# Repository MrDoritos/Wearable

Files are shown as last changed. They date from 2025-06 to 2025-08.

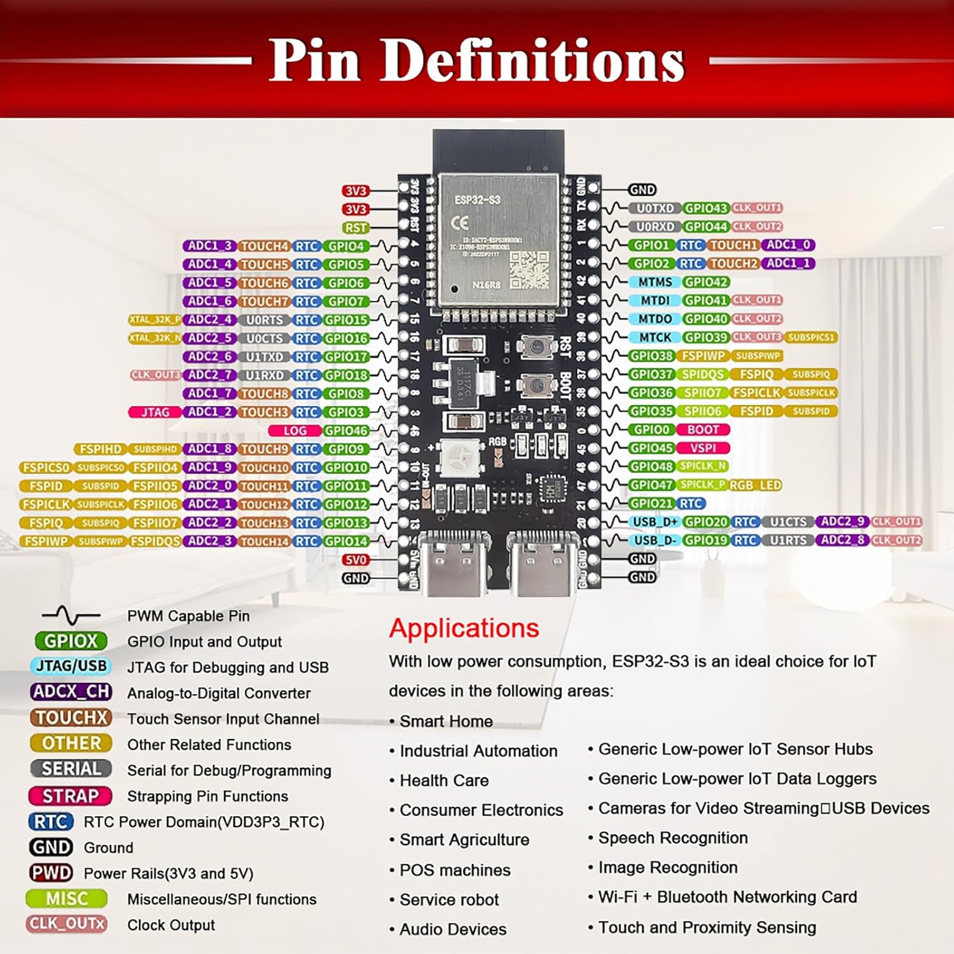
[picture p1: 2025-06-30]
Pics/ESP32 S3 Pinout - 8150a4JlqrL._AC_SL1500_.jpg

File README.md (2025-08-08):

# Wearable

Open source activity and environment tracking and logging device. Works fully offline.

## Features

- GPS location and time synchronization
- Humidity, temperature, and pressure monitoring
- Monitor the level of various gases, such as CO, CO2, VOCs, NH3, NO2, and other hydrocarbons
- UV exposure tracking
- 128x128 OLED display, for high contrast and low power draw
- Piezo and haptic user feedback
- Accelerometer, gyroscope, magnetometer information
- Logging to SD card
- Screen timeout and input lock
- Automatic screen brightness from the ambient light sensor
- Heart rate, blood oxygen (SpO2), and breathing rate
- Minimal loading time

## User interface

- GPS map (only plotted, no map)
- Travel distance and pedometer (step counter)
    - Also available in the stopwatch, which offers splits and history
- Log view
    - Short term, about 10s of information
    - Long term, any amount of information at any specified interval
- Delay free, low latency interface
- Full screen clock interface
- Battery level and time and date visible
- Dynamic interface layout, the size of elements can change

## What's missing

A lot, only a month of programming really went into it. It wasn't sloppy though, and it is quite easy to add and remove features. Some power saving features are missing entirely.

## How much

$200 in parts, but sewing and 3D printing will take some time.

## Parts

- ESP32 S3
- TLV1117 3.3V LDO SOT-223 regulator
- JST 500 or 1200 mAh battery
- GME128128 I2C SH1107 1.5" Monochrome OLED
- BME688
- BerryGPS-IMU v4
- 10mm Piezo, 10mm Vibration motor
- 5x 4.25mm SMD buttons
- 30 AWG silicone wire
- 34 AWG enameled wire
- Stretchy fabric, stretchy thread, non-strechy thread
- MAX30102
- LTR390-UV

Resin printed button caps.

3D printed fabric frames and button holder.

It is best to remove unnecessary connectors.

## In the future

Not waterproof. Most sensors can move to a single board. MAX30102 can be minified. Buttons could be silicone. No frame for the LTR390-UV prevents consistent light measurements. No ammeter to track battery usage.

## Why

Internship project

## Credits

- DFRobot, MAX30102, BMP388
- RocketManRC, u-blox-m8
- Adafruit, LTR390, LSM6DSL, LIS3MDL, inspiration for display driver
- Mozilla, CSS documentation
- Espressif, ESP IDF, HAL for ESP32 S3

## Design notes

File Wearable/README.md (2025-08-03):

# Source for ESP32 controller for Wearable

`g++ imgconv.cpp -o imgconv.o && ./imgconv.o 1 1 ../fonts/fixedsys-excelsior-301.ttf_16x16.png`

`objcopy -I binary -O elf64-x86-64 --rename-section .data=.rodata,alloc,load,readonly,contents fixedsys.bin binary.o`

`g++ binary.o emulator.cpp -o emulator.o console/console.ansi.cpp -g -z noexecstack`

## To-Do

- [ ] UI library
    - [x] Layout
    - [x] Auto sizing
    - [x] Display timeout
    - [ ] Overlays
    - [ ] Popovers
    - [ ] Footer
    - [ ] Focus
- [ ] ESP32
    - [x] Basic functions
        - [x] Display
        - [x] Buttons
        - [x] 3.7v \- 4.2v input
        - [x] Battery sense
    - [ ] Display interface
        - [ ] Async buffer flush
        - [x] Rotation
        - [ ] Screen wake on arm lift and hold
    - [ ] Vibration
        - 3.3V, starting voltage 2.3V
        - less than 75mA, starting current 120mA
    - [ ] Buzzer
    - [ ] LED status
- [ ] Logging
    - [x] SD Card
        - [x] Remaining / total size
        - 3.3v
        - CS pullup to 3.3v permanently, if display remains I2C
    - [ ] Sync GPS time to exported log
- [ ] Sensors
    - [ ] GPS IMU
        - [ ] Magnetometer
            - 0x1C
            - LIS3MDL
        - [x] Gyroscope and Accelerometer
            - 0x6A
            - LSM6DSL
        - [ ] Barometer
            - 0x77
            - BME388
        - [x] GPS
            - 3.3V
            - 0x42
            - CAM-M8
        - [x] GPS time sync
        - 0.040A @ 5v -> 0.2W
    - [ ] LTR-390 UV
        - [ ] UV daily exposure alert
        - [x] Ambient light for auto brightness
        - 400 kHz I2C
        - 3.3V input voltage
        - 100 uA max duty cycle
        - 1 uA standby
        - 5-10ms standby to active
        - [x] UVS/ALS
            - 13 - 20 bits resolution
            - 1:18,000,000 dynamic range
        - UV spectral response 300-350 nm
        - 1 field at a time, mode switch required
    - [ ] BME688
        - [ ] CO2eq ppm
        - [ ] IAQ (0 - 500)
        - [ ] bVOC ppm
            - Breath VOCs
        - [ ] Gas scan results (%)
            - Hydrogen sulfide (H2S)
            - Ethanol (EtOH)
            - Carbon monoxide (CO)
            - 10 to 30 seconds
        - [ ] Humidity (0-100%)
            - accuracy 3%
        - [ ] Temperature
            - 0.01 C output resolution (0.5C accuracy 0-65C)
        - [ ] Pressure (0 - 200000 Pa)
            - 0.18 Pa output resolution (1.2cm)
        - 3.9 mA gas scan
        - 90 uA P/T/H
    - [ ] MICS-6814
        - [ ] Gases
            - [ ] Carbon monoxide (CO) (1-1000 ppm)
            - [ ] Nitrogen dioxide (NO2) (0.05 - 10 ppm)
            - [ ] Ethanol (C2H5OH) (10-500 ppm)
            - [ ] Hydrogen (H2) (1-1000 ppm)
            - [ ] Ammonia (NH3) (1-500 ppm)
            - [ ] Methane (CH4) >1000ppm
            - [ ] Propane (C3H8) >1000ppm
            - [ ] Iso-butane (C4H10) >1000ppm
        - [x] Reality
            - [x] CO (RED reducing gases)
            - [x] NO2 (OX oxidizing gases)
            - [x] NH3
            - Only relative readings. Typical resulting voltages are CO=2.4V NO2=1.7V NH3=2.2V. May work on 3.3v with resistor swapping
            - Heating current is 30mA.. 88mW (5V)
            - Must be read with analog
    - [ ] MAX30102
        - Onboard 3.3V regulator
        - 600 uA
        - 0.7 standby
        - HbO2 oxygenated hemoglobin absorbs infrared
        - Internal temperature sensor
            - 1 C accuracy (-40 - 85C)
        - 400kHz I2C
- Power by module
    - ESP32
        - 40 mA
        - 3.3V reg
    - GPS
        - 40 mA
        - VBAT possible
    - MAX30102
        - 1 mA
        - 3.3V reg
    - GME128128
        - 60 mA
        - VBAT ok
    - BME688
        - 4 mA
        - VBAT possible
    - MiCS-6814
        - 30 mA
        - VBAT possible
    - LTR390-UV
        - 1 mA
        - VBAT possible, may require 3.3v?
    - SD Card
        - 100 mA default mode, verify!
    - Haptics
        - 60 mA.. use VBAT if possible

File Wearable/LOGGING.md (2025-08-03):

# Logging

### Polling Rates

- Each module should synchronize their fields?
- How expensive are SD card flushes?
- Long term data can use an additional buffer, these are for immediate information.
- Screen flush always blocks 36ms, all UI operations block for ~50ms total, but can be split up.
- Sample 2x the frequency of the desired field required to be processed
- I planned on having the polling rate be configured in the UI, without element focus it can't be done
- Time stretching with display on is okay, since with display off it's not an issue

Module|Log Field|Polling Rate|Buffer Size
------|---------|------------|-----------
Battery|Voltage|1000ms (1Hz)|10
MiCS-6814|CO Voltage|1000ms (1Hz)|10
-|NH3 Voltage|-|10
-|NO2 Voltage|-|10
CAM-M8|Latitude|1000ms (1Hz)|100
-|Longitude|-|100
-|Altitude|-|10
-|Bearing|-|10
-|PDOP|-|10
-|Ground Speed|-|10
-|Horizontal Accuracy|-|10
-|Vertical Accuracy|-|10
-|Time Accuracy|-|10
-|Odometer|-|10
IMU|Accelerometer X|10ms (100Hz)|1000
-|Accelerometer Y|-|-
-|Accelerometer Z|-|-
-|Gyroscope X|-|-
-|Gyroscope Y|-|-
-|Gyroscope Z|-|-
-|Pedometer|1000ms (1Hz)|10
BME688|Humidity|1000ms (1Hz)|10
-|Temperature|-|-
-|Pressure|-|-
-|VOC|-|-
-|AQI|-|-
-|CO2|-|-
-|Gas Scan H2S|30000ms (0.0333Hz)|10
-|Gas Scan EtOH|-|-
-|Gas Scan CO|-|-
BMP388|Pressure|1000ms (1Hz)|10
LTR390|ALS|1000ms (1Hz)|10
-|Lux|-|-
-|UVS|-|-
-|UVI|-|-
MAX30102|IR value|50ms (20Hz)|200
-|Red value|-|-
-|Heart Rate|1000ms (1Hz)|10
-|SpO2|-|-

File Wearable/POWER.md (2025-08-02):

# Power Usage Information

### Aug 1 2025

#### Current Device List

- ESP32 S3
    - Core 1 idle
    - Core 0, no sleep, 80 MHz
    - ULP core inactive
    - AMS1117 replaced with TLV1117
- TLV1117
    - SOT223 package
    - 3.3v regulator
    - Low Iq
    - LDO
- LP602535
- GPS/IMU
    - CAM-M8
        - 1s/fix
    - LIS3MDL
    - LSM6DSL
    - BME388
- LTR390
    - 16-Bit resolution
    - 25ms measurement rate
- GME128128
    - SH1107

#### TLV1117 3.3V Regulator

Field|Min|Typ|Max|Unit
-----|---|---|---|----
Input Voltage|2||5.5|V
Output Current|||1.1|A
Dropout Voltage 200mA||115||mV
Dropout Voltage 500mA||285||mV
Dropout Voltage 800mA||455||mV
Dropout Voltage 1000mA||570|800|mV
Quiescent Current 0mA||50||μA
Quiescent Current 200mA||150||μA
Quiescent Current 500mA||300||μA
Quiescent Current 800mA||450||μA
Quiescent Current 1000mA||500||μA
Thermal shutdown||165||°C
Thermal reset||145||°C
Operating temperature|-40||125|°C

#### LP602535 500mAh LiPo

Field|Min|Typ|Max|Unit
-----|---|---|---|----
Capacity|500|510||mAh
Energy Capacity||1.85||Wh
Nominal Voltage||3.70||V
Operating Voltage|2.75||4.20|V
Charging Voltage|||4.20±0.050|V
Charging Current|||250|mA
Discharge Current|||500|mA
Discharge Cut-off Voltage||2.75||V
Internal Impedance|||200|mΩ
Cycle Life||500||cycles
Overcharge Detection||4.275||V
Overdischarge Detection||2.75||V
Overcurrent Detection|2||4.5|A
Charge Temperature|0||45|°C
Discharge Temperature|-20||60|°C

#### GPS/IMU

Field|Min|Typ|Max|Unit
-----|---|---|---|----
4.5V on 5V input|39/170|40/170|42/180|mA/mW
3.3V on 5V input|39/130|40/130|44/140|mA/mW
3.3V on 3.3V input|39/130|40/130|42/140|mA/mW

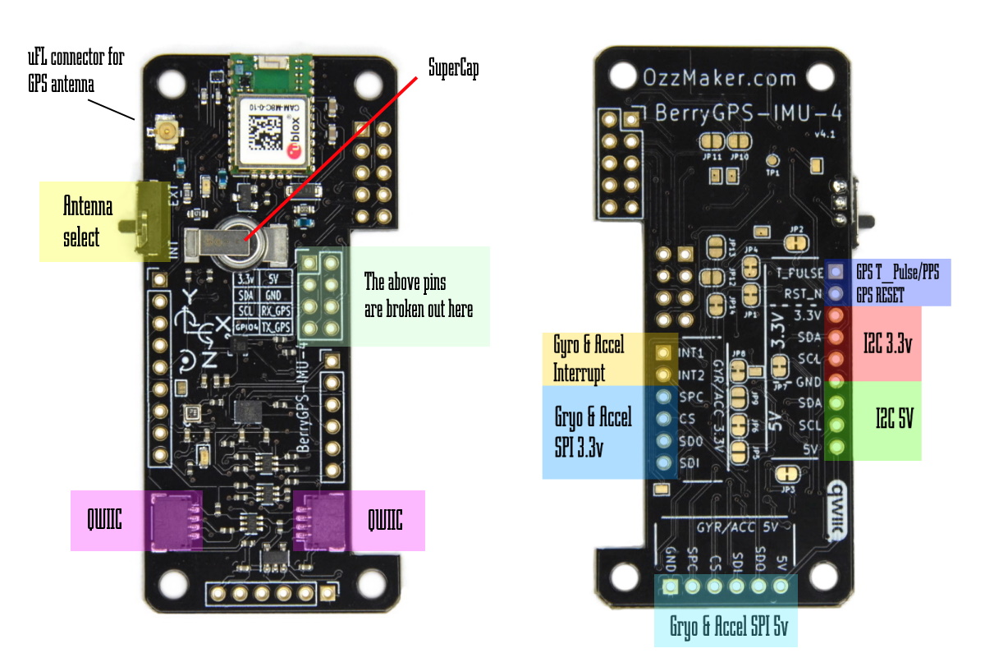
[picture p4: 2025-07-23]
Pics/BerryGPS-IMUv4Pinout2-1600.jpg

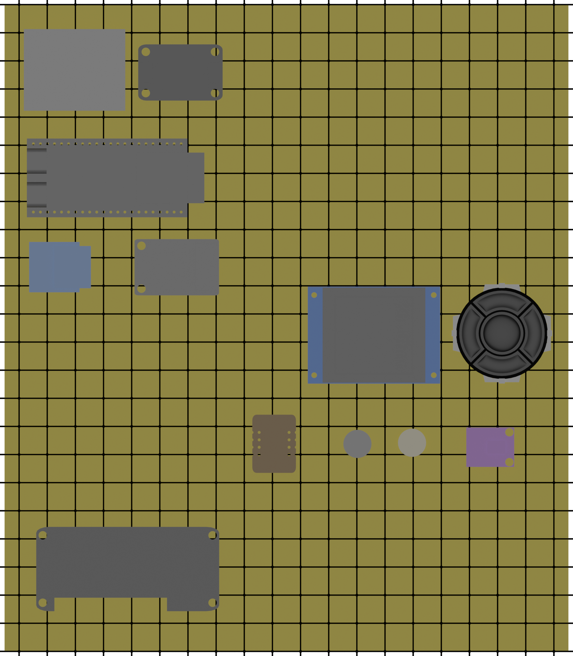
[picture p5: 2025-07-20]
layout2.png

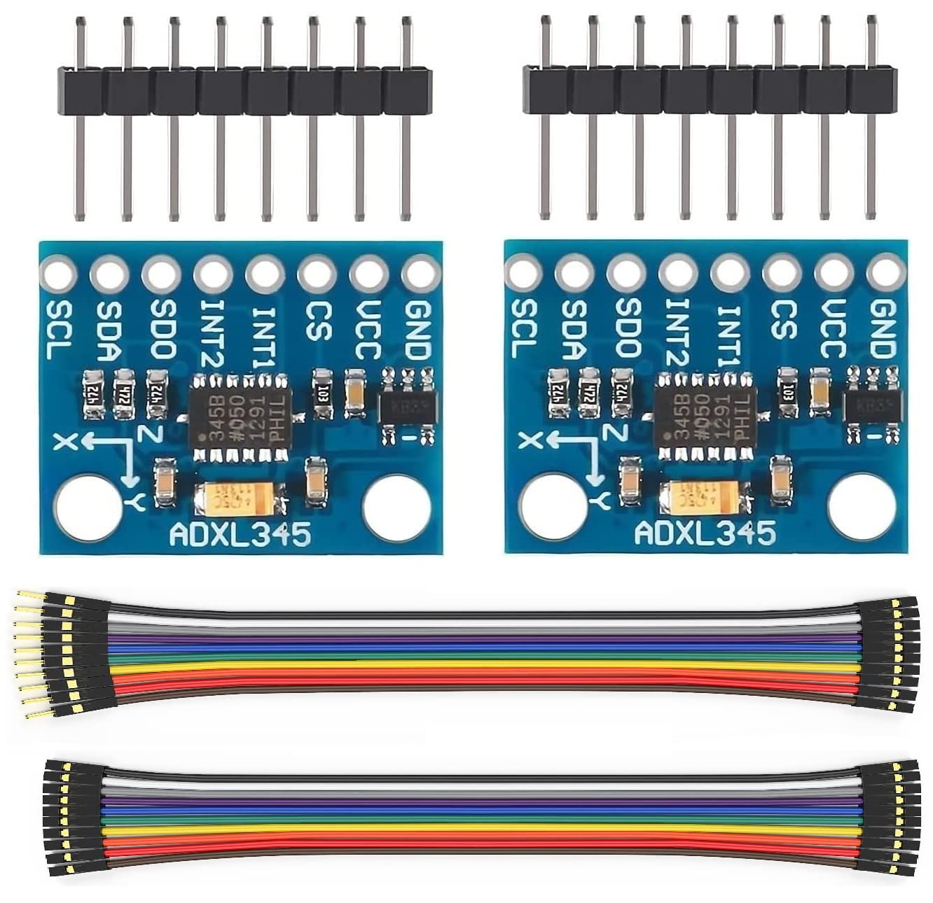
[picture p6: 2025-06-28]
Pics/71FKNZfBxHL._SL1332_.jpg

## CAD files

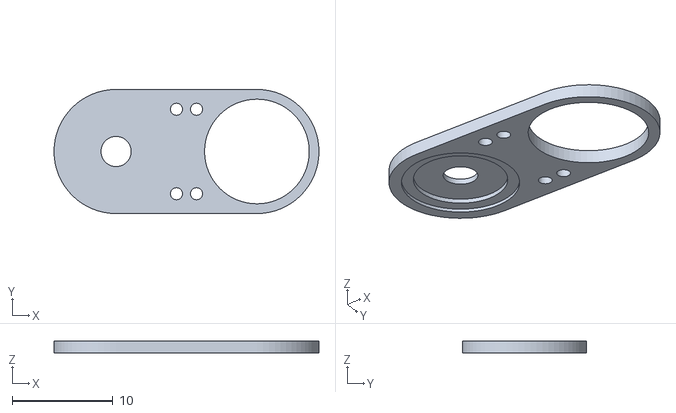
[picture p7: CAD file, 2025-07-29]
stl/Parts Piezo Resonator and Haptics.stl
26.3 x 12.3 x 1.20

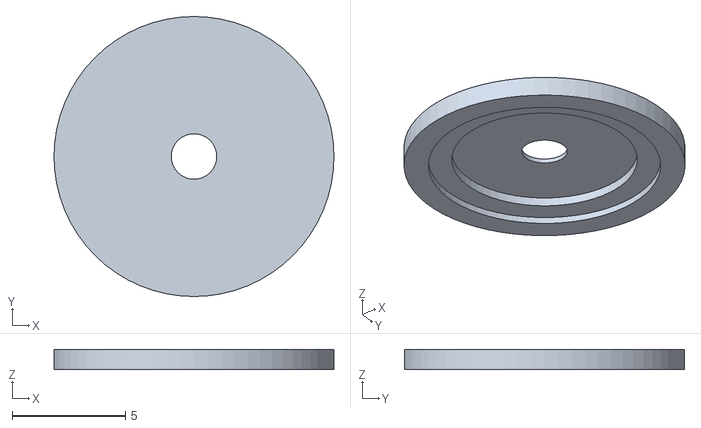
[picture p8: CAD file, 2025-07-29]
stl/Parts Piezo Resonator.stl
12.3 x 12.3 x 0.9

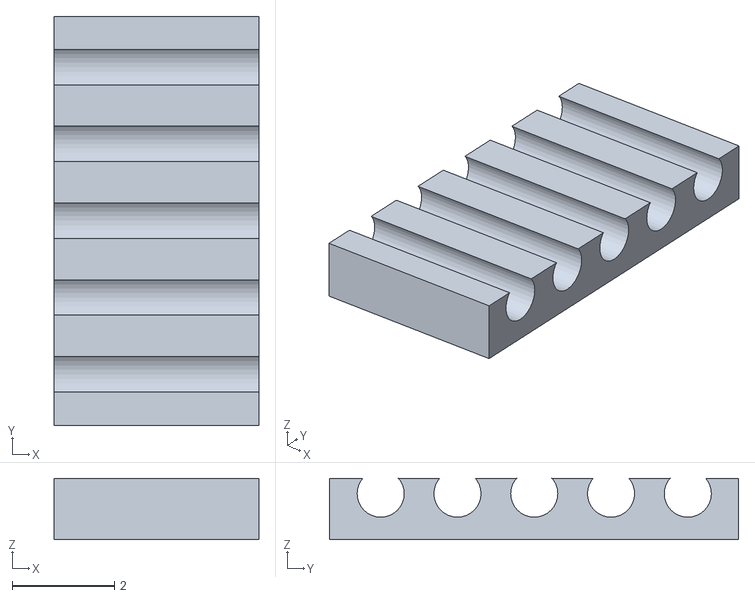
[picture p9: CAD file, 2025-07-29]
stl/Parts Wire Guide.stl
4.00 x 7.99 x 1.20

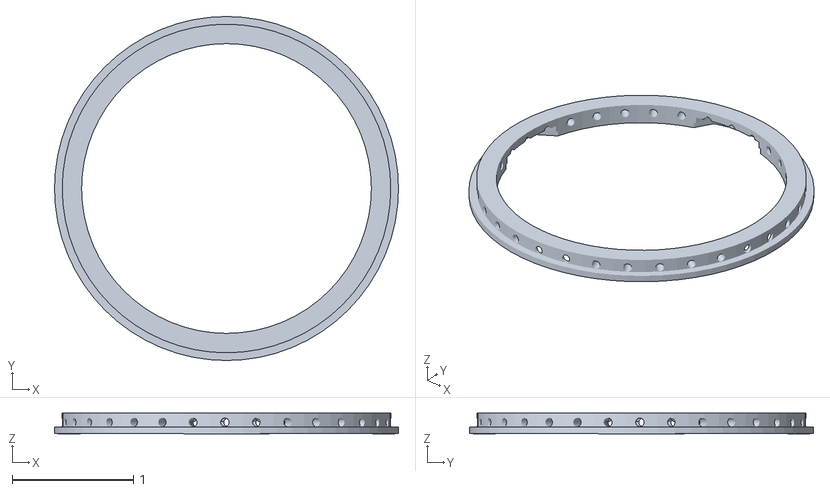
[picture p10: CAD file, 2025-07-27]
stl/dpad frame.stl
2.84 x 2.84 x 0.172

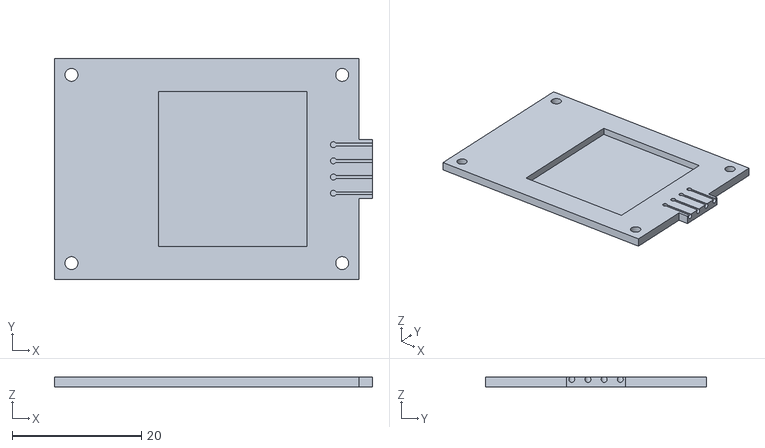
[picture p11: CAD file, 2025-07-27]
stl/Parts OLED Back.stl
49.2 x 34.1 x 1.60

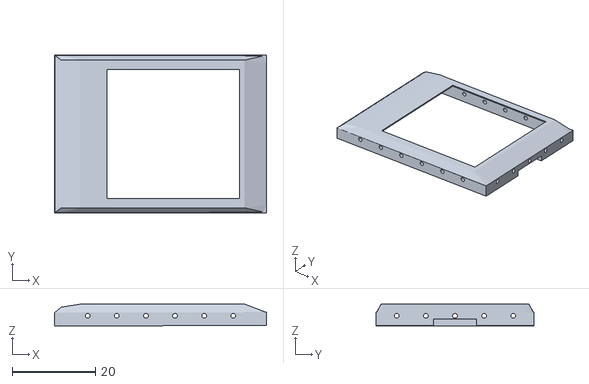
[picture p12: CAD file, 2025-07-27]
stl/Parts OLED Cover.stl
51.0 x 38.0 x 5.24

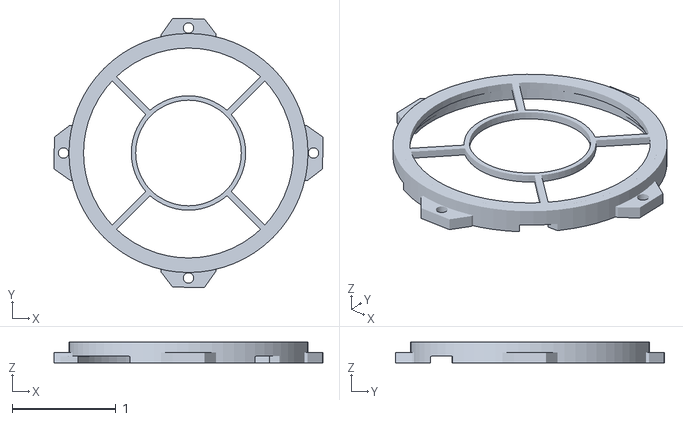
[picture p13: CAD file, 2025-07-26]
stl/dpad holder.stl
2.59 x 2.59 x 0.201

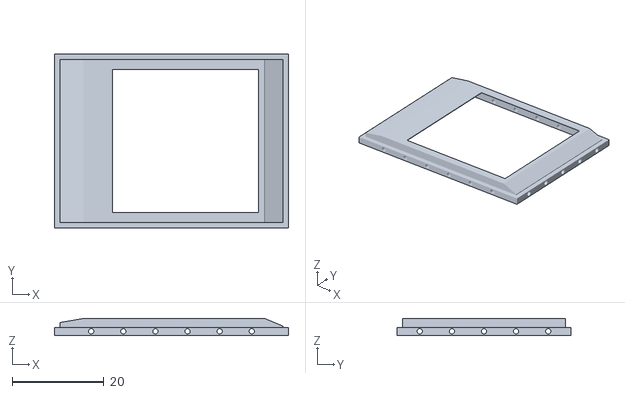
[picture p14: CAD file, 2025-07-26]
stl/Parts OLED Frame New.stl
51.0 x 38.0 x 3.74

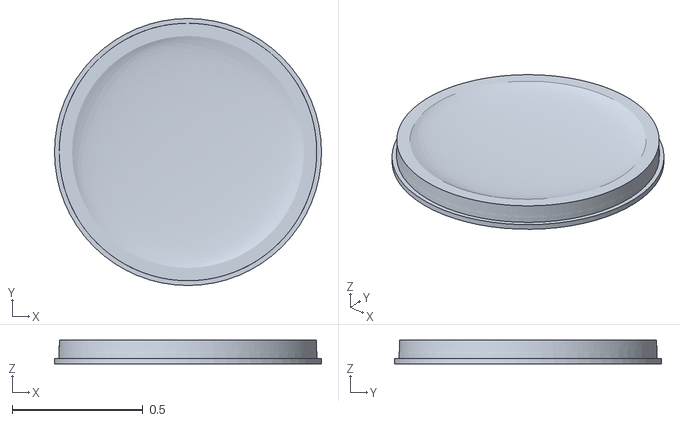
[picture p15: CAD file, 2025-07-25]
stl/dpadenter.stl
1.02 x 1.02 x 0.091

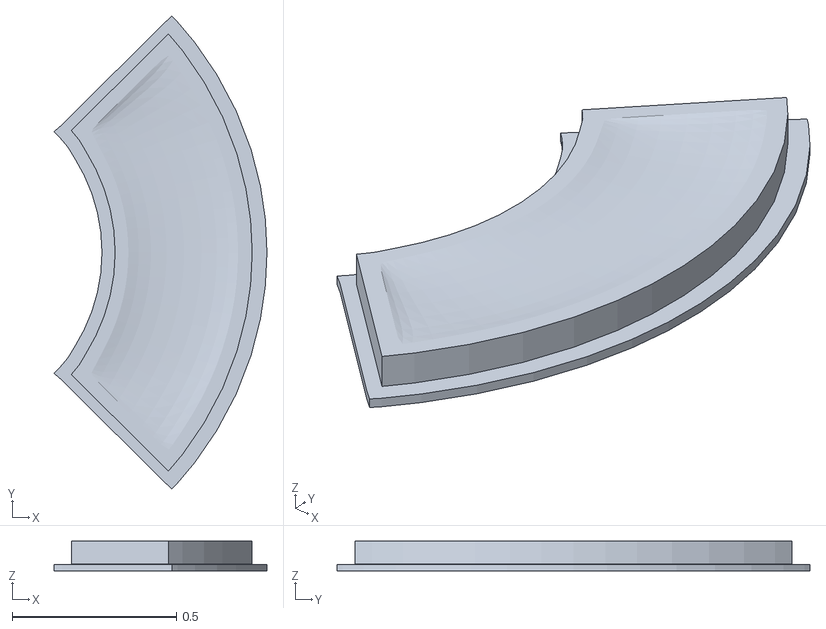
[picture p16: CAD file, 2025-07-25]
stl/dpadarrow.stl
0.648 x 1.44 x 0.0911

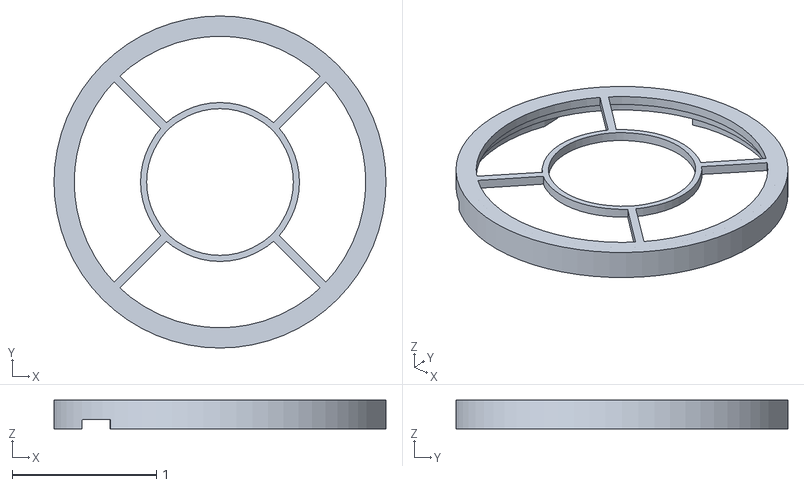
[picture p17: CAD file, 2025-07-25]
stl/Parts SMD Button Housing.stl
2.30 x 2.30 x 0.201

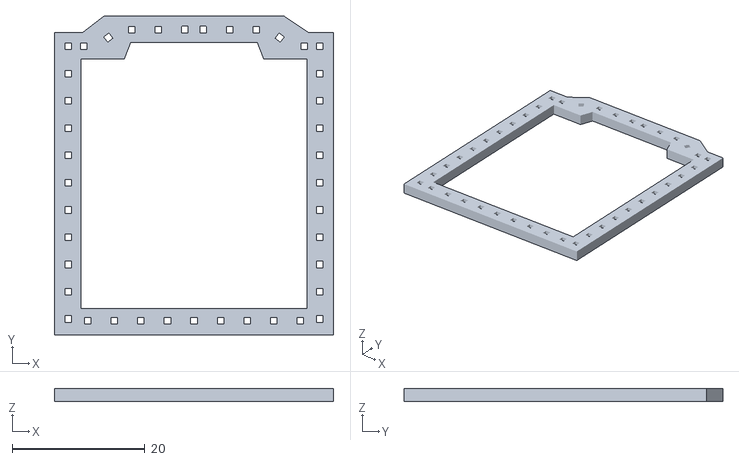
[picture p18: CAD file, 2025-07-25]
stl/Parts OLED Frame.stl
42.0 x 48.0 x 2.00

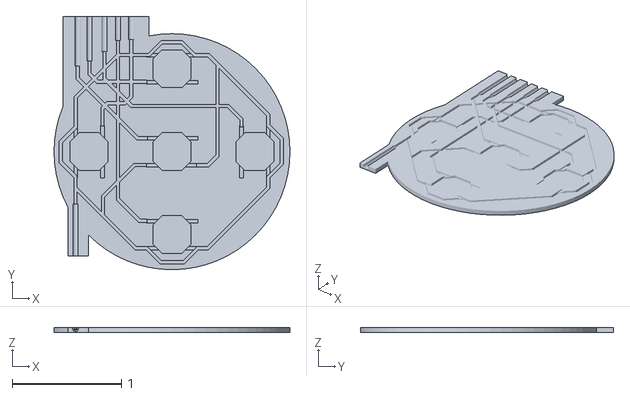
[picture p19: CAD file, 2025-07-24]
stl/dpad Button Board.stl
2.16 x 2.32 x 0.047

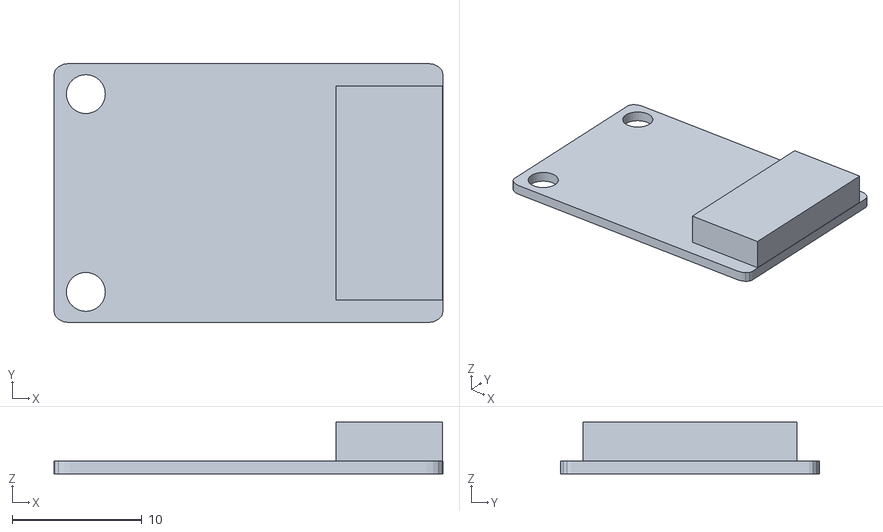
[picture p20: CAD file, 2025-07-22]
stl/PartsBME688_PCB.001.stl
30.0 x 20.0 x 4.00

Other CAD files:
stl/PartsLipo_500mAh.001.stl
stl/PartsMAX30102_PCB.001.stl
stl/PartsSD_card_PCB.001.stl
stl/PartsBerryGPS-IMU_PCB.001.stl
Parts.blend
dpad.blend
stl/ADA254.stl
stl/ADXL345.stl
stl/AHT21.stl
stl/BME280.stl
stl/ESP8266.stl
stl/GT-U7.stl
stl/Lipo 1200.stl
stl/Lipo 500.stl
stl/MAX30102.stl
stl/PartsESP32_PCB.001.stl
stl/PartsHaptic_Motor.001.stl
stl/PartsLTR390-UV_PCB.001.stl
stl/PartsMICS-6814_PCB.001.stl
stl/PartsPiezo.001.stl
stl/dpad.stl
stl/dpadbuttondemo.stl
stl/dpadring.3mf
stl/dpadring.stl
stl/sh1107 inner.3mf
stl/sh1107 inner.stl
stl/sh1107.stl

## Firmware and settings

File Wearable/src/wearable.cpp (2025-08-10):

#include <stdio.h>
#include <inttypes.h>
#include "esp_system.h"
#include "freertos/FreeRTOS.h"
#include "freertos/task.h"

#include "displaybuffer.h"
#include "texture.h"
#include "font.h"
#include "ui.h"
#include "sprites.h"
#include "user_inputs.h"
#include "wbl_func.h"
#include "ui_func.h"
#include "ui_log.h"
#include "display_timeout.h"
#include "gps.h"
#include "ui_gps.h"
#include "gps_imu.h"
#include "ui_imu.h"
#include "wbl_system.h"
#include "ltr390.h"
#include "ui_sysinfo.h"
#include "mics6814.h"
#include "sdcard.h"
#include "peripheral_log.h"
#include "ui_peripheral_log.h"
#include "ui_gps_log.h"
#include "ui_footer.h"
#include "ui_distancetracker.h"
#include "ui_therock.h"

using namespace wbl;
using namespace Sprites;

UI::ElementBaseT<DisplayTexture> test(display);
UI::ElementInlineSpritesT<DisplayTexture, Atlas> spinline(display);
UI::ElementInlineTextT<DisplayTexture, MinifontProvider> TEXT(display, minifont);
UI::ScreenClockT<DisplayTexture> uiclock(display);
UI::ElementRootT<DisplayTexture> uiroot(display);
auto txt = UI::ElementInlineTextT<DisplayTexture, MinifontProvider>(display, minifont);
UI::ElementBatteryT<DisplayTexture> uibattery(display);
UI::ElementDateTimeT<DisplayTexture> uidatetime(display);
UI::ElementBaseT<DisplayTexture> boxtest(display);
UI::ElementBaseT<DisplayTexture> boxtest2(display);
UI::ElementBaseT<DisplayTexture> header(display);
UI::ScreenBaseT<> mainscreen("Main");
UI::ScreenBaseT<> clockscreen("Clock");
UI::ScreenBaseT<> settingscreen("Settings");
LoopBuffer sinelog, squarelog, sawlog, voltlog;
UI::ElementLogT<DisplayTexture, DataLog> e_sinelog(display, sinelog), e_squarelog(display, squarelog), e_sawlog(display, sawlog), e_voltlog(display, voltlog);
UI::ElementLockIconT<DisplayTexture> e_lockicon(display);
UI::ScreenFooterT<> gpsscreen(display, "GPS Info");
UI::ElementGPST<DisplayTexture> uigps(display);
UI::ScreenFooterT<> imuscreen(display, "IMU Info");

UI::ElementIMUT<DisplayTexture> uiimu(display);
UI::ScreenBaseT<> sysinfoscreen("System");
UI::ElementSysInfoT<DisplayTexture> uisysinfo(display);
LoopBuffer colog, nh3log, no2log;
//UI::ElementLogT<DisplayTexture, DataLog> e_colog(display, colog), e_nh3log(display, nh3log), e_no2log(display, no2log);
UI::ElementPeripheralLogAutoT<DisplayTexture, DLMICS6814ST, uint16_t, 0> e_colog(display, wbl::log.mics6814_st);
UI::ElementPeripheralLogAutoT<DisplayTexture, DLMICS6814ST, uint16_t, 1> e_nh3log(display, wbl::log.mics6814_st);
UI::ElementPeripheralLogAutoT<DisplayTexture, DLMICS6814ST, uint16_t, 2> e_no2log(display, wbl::log.mics6814_st);
UI::ScreenFooterT<> gasscreen(display, "Gases");
UI::ElementPeripheralLogAutoT<DisplayTexture, DLBatteryST, uint16_t, 0, UI::ValueBases::Voltage> e_pbatterylogst(display, wbl::log.battery_st);
UI::ElementPeripheralLogAutoT<DisplayTexture, DLBatteryLT, uint16_t, 0, UI::ValueBases::Voltage> e_pbatterylog(display, wbl::log.battery_lt);
UI::ScreenBaseT<> gpsview("GPS");
UI::UIGPSLogT<DisplayTexture, DLCAMM8ST> uigpsst(display, wbl::log.camm8_st);
UI::UIGPSLogT<DisplayTexture, DLCAMM8LT2> uigpslt(display, wbl::log.camm8_lt2);
UI::ElementFooterT<DisplayTexture> uigpsfooter(display, "GPS View");
UI::ScreenBaseT<> distscreen("Tracker");
UI::UIDistanceTrackerT<DisplayTexture> uitracker(display);
UI::ScreenBaseT<> rockscreen("The Rock");
UI::ElementTheRockT<DisplayTexture> e_therock(display);


void demo() {
    wbl::log.update();

    bool has_input = false;
    if (!displayTimeout.lock_key_state(dpad.enter.is_held()))
        has_input = dispatch_input_events(uiroot, dpad);
    else
        dpad.update();

    displayTimeout.update(has_input);

    wbl_system.update();

    uiroot.step();

    static int cnt = 0;
    int64_t t = micros();
    if (cnt++ % 4 == 0) {
        if (wbl::log.ltr390_st.size() > 0) {
            DPLTR390ST stp = wbl::log.ltr390_st.get(-1);
            e_squarelog.push_back(t, stp.uvi*10.0f);
            e_sinelog.push_back(t, stp.lux);
            wbl_system.setDisplayBrightness(stp.lux);
        }
        e_sawlog.push_back(t, (uu)(int(t/5000)%1000));
    }

    if (displayTimeout.is_display_off())
        wbl::log.sleepTillNextPoll();

    #ifdef __linux__
    delay(30);
    #endif
}

void init() {
    //uiroot.setDebug(true);
    WBL_D("UI Init");
    using namespace UI;
    using DElem = UI::ElementT<DisplayTexture>;
    using FElem = UI::ElementFocusT<DisplayTexture>;
    static DElem block(display, "block");
    static DElem inner(display, "inner");
    static DElem block2(display, "area");
    static DElem inlineblock(display, "inline");
    static DElem inlineblock2(display, "sprites");
    static DElem inlineblock3(display, "right");
    static DElem inlineblock4(display, "left");
    static DElem block3(display, "after");

    static FElem focustest(display, "one");
    static FElem focustest2(display, "two");
    static FElem focustest3(display, "three");

    static UI::StyleInfo styles { .display{INLINE}, .width{{25,PERC}}, .height{25} };

    focustest << styles;
    focustest2 << styles;
    focustest3 << styles;
    //settingscreen << focustest;
    //settingscreen << focustest2;
    //settingscreen << focustest3;
    settingscreen << e_sinelog;
    settingscreen << e_squarelog;
    settingscreen << e_sawlog;
    settingscreen << e_voltlog;
    gpsscreen << uigps;
    imuscreen << uiimu;

    StyleInfo screenremaining { .height{92} };

    block << UI::StyleInfo { .height{26} };
    inner << StyleInfo {.height {14}};
    block2 << UI::StyleInfo { .width{32}, .height{26} };
    inlineblock << UI::StyleInfo { .display{INLINE}, .width {40}, .height{26} };
    inlineblock2 << UI::StyleInfo { .align{RIGHT}, .display{INLINE}, .width {32}, .height{20}, .margin{2} };
    inlineblock3 << UI::StyleInfo { .align{RIGHT}, .display{INLINE}, .width {20}, .height{10}, .margin{2} };
    inlineblock4 << UI::StyleInfo { .display{INLINE}, .width{20}, .height{30}, .margin{2} };
    block3 << StyleInfo { .width {30}, .height{20} };
    e_lockicon << StyleInfo{.display{INLINE}, .overflow{AUTO,AUTO}} << "lock";
    uigps << StyleInfo { .height{92}, .overflow{AUTO,AUTO} } << "GPS";
    uiimu << StyleInfo { .height{92} } << "IMU";
    StyleInfo logstyle = { .display{INLINE}, .width {62}, .height{40}, .margin{1} };
    
    uisysinfo << StyleInfo { .height{80} };
    sysinfoscreen << uisysinfo << e_pbatterylog << e_pbatterylogst;

    e_sawlog << logstyle << "saw";
    e_voltlog << logstyle << "volts"; 
    e_sinelog << logstyle << "sine";
    e_squarelog << logstyle << "square";

    StyleInfo gaslogstyle = { .height{32}, .margin{1,0,0,0} };
    e_colog << gaslogstyle << "CO";
    e_nh3log << gaslogstyle << "NH3";
    e_no2log << gaslogstyle << "NO2";
    e_pbatterylog << StyleInfo { .display{INLINE}, .width {96}, .height{32}, .margin{1,1,0,0} } << "VBAT";
    e_pbatterylogst << StyleInfo { .display{INLINE}, .width {30}, .height{32}, .margin{1,0,0,0} } << "VBAT";
    gasscreen << e_colog << e_nh3log << e_no2log;
    distscreen << uitracker;

    uigpslt << StyleInfo { .display{INLINE}, .width {96}, .height{96} } << "GPSLT";
    uigpsst << StyleInfo { .display{INLINE}, .width {32}, .height{64} } << "GPSST";
    gpsview << uigpslt << uigpsst << uigpsfooter;

    uiroot << UI::StyleInfo { .width{128}, .height{128} };

    block << inner;

    /*
    uiroot << block;
    uiroot << block2;
    uiroot << inlineblock;
    uiroot << inlineblock2;
    uiroot << inlineblock3;
    uiroot << inlineblock4;
    uiroot << block3;

    uiroot.resolve_layout();
    */

    //uiroot << Size { 0, 0, 128, 128 };
    test << Origin { 4, 30 };
    //txt << Size { 32, 64, 64, 64 };
    //txt << UI::StyleInfo { .wrap{UI::WRAP} };
    //uiclock << Size { 16, 16, 97, 97 };
    //uiclock << StyleInfo { .width{96}, .height{96}, .margin{16,4} };
    clockscreen << StyleInfo { .width{{100,PERC}}, .height{{100,PERC}} };
    uiclock << StyleInfo { .align{CENTER}, .width{{85,PERC}}, .height{{85, PERC}} };
    TEXT << Origin { 12, 16 };
    test.wrap = (UI::WrapStyle)(UI::WrapStyle::WRAP | UI::WrapStyle::TRIM_SPACE);
    test << Size { 32, 30, 64, 64 };
    spinline << HEART << BATTERY << UI::StyleInfo { .wrap{UI::NOWRAP} };
    //uibattery << Size {0,0,32,16};
    //uidatetime << Size {49, 0, 79, 12} << UI::StyleInfo {.wrap{UI::WRAP}};
    uibattery << UI::StyleInfo { .align{LEFT}, .wrap{NOWRAP}, .display{INLINE}, .overflow{AUTO} };
    uidatetime << UI::StyleInfo { .align{RIGHT}, .wrap{NOWRAP}, .display{INLINE}, .overflow{AUTO} };
    boxtest << Size { 8, 13, 5, 5 };
    boxtest2 << Size { 9, 14, 3, 3 };
    txt << StyleInfo { .align{CENTER}, .width{{70}}, .margin{4} };
    uiclock.use_milliseconds = true;

    TEXT.text = "Hello UI";
    txt.text = "SOME TEST TEXT\n VERY FINE text\n for very small values 0123456789 \% voltage 4.2v !\"#$%&'()*+,-./:;<=>?@[\\]^_`{|}~";

    spinline.on_content_size(nullptr);
    TEXT.on_content_size(nullptr);

    spinline.resolve_layout();
    TEXT.resolve_layout();

    //screenclock.addHeader(header);
    //screenclock << uiclock;
    //screenclocknoheader << txt;

    //uiroot << uibattery;
    //uiroot << uidatetime;
    txt.name = "txt";
    header.name = "header";
    uibattery.name = "battery";
    uidatetime.name = "datetime";
    clockscreen.name = "clockscreen";
    mainscreen.name = "mainscreen";
    uiclock.name = "clock";
    uiroot.name = "root";

    clockscreen.show_header = false;
    rockscreen.show_header = false;

    rockscreen << e_therock;

    header << uibattery;
    header << e_lockicon;
    header << uidatetime;
    //uiroot << header;
    //uiroot << uiclock;
    //uiroot << screenclock;
    //uiroot << screenclocknoheader;
    clockscreen << uiclock;
    mainscreen << txt;
    //mainscreen.set_left(clockscreen);
    //mainscreen.set_right(settingscreen);
    clockscreen.set_left(rockscreen);
    settingscreen.set_left(clockscreen);
    settingscreen.set_right(gpsscreen);
    gpsscreen.set_right(imuscreen);
    imuscreen.set_right(sysinfoscreen);
    sysinfoscreen.set_right(gasscreen);
    gasscreen.set_right(gpsview);
    gpsview.set_right(distscreen);

    uiroot.set_header(header);
    //uiroot.set_screen(mainscreen);
    //uiroot.set_screen(settingscreen);
    //uiroot.set_screen(gpsscreen);
    uiroot.set_screen(imuscreen);
    //uiroot.set_screen(sysinfoscreen);
    //uiroot.set_screen(gasscreen);
    //uiroot.set_screen(gpsview);
    //uiroot.set_screen(distscreen);

    WBL_D("Screen set");

    uiroot.dispatch(EventTypes::CONTENT_SIZE);
    uiroot.resolve_layout();

    WBL_D("First layout");

    for (int i = 0; i < 3; i++)
        wbl_system.getBatteryVoltageMean();
    uibattery.set_battery_level(wbl_system.getBatteryLevel());

    WBL_D("UI endinit");
}

extern "C" {
void app_main() {
    if (wbl_system.init() != ESP_OK) {
        printf("Failed to initialize system\n");
        goto end;
    }
    //wbl_system.acquirePMLock();
    //wbl_system.releasePMLock();
    puts("Initialized system");
    if (mics6814.init() != ESP_OK) {
        printf("Failed to initialize mics6814\n");
        goto end;
    }
    puts("Initialized MiCS-6814");
    wbl_system.beginHapticFeedback(0.5, 500);
    dpad.init();
    puts("Initialized DPAD");
    if (gps.init() != ESP_OK) {
        printf("Failed to initialize gps\n");
        goto end;
    }
    puts("Initialized GPS");
    if (gpsimu.init() != ESP_OK) {
        printf("Failed to initialize imu\n");
        goto end;
    }
    puts("Initialized IMU");
    if (ltr390.init() != ESP_OK) {
        printf("Failed to initialize ltr390\n");
        goto end;
    }
    puts("Initialized LTR390");
    if (sdcard.init() != ESP_OK) {
        printf("Failed to initialize sdcard\n");
        goto end;
    }
    puts("Initialized SDCard");
    if (wbl::log.init() != ESP_OK) {
        printf("Failed to initialize log\n");
        goto end;
    }
    puts("Initialized log");
    init();
    puts("Initialized UI");
    if (display.init() != ESP_OK) {
        printf("Failed to initialize display\n");
        goto end;
    } else {
        printf("Display initialized\n");
        display.clear(0);
        WBL_D("Display clear");
        wbl_system.setDisplayRotation(DISPLAY_ROTATION);
        WBL_D("Display rotation");
        //gps.update();
        //gps.setSystemTime();
        displayTimeout.update(true);
        while (1) {
            demo();
            vPortYield();
        }
    }

    end:;

    fflush(stdout);
    
    delay(1000);

    esp_restart();
}
}

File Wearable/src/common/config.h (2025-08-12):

#pragma once

#include "types.h"

#define I2C_BUS_0_SDA   GPIO_NUM_6
#define I2C_BUS_0_SCL   GPIO_NUM_5

#define I2C_BUS_1_SDA   GPIO_NUM_48
#define I2C_BUS_1_SCL   GPIO_NUM_45

#define I2C_DISPLAY_FREQ 1000000
#define I2C_SH1107_ADDR 0x3C

#define I2C_CAMM8_FREQ 400000
#define I2C_CAMM8_ADDR 0x42

#define I2C_LIS3MDL_FREQ 400000
#define I2C_LIS3MDL_ADDR 0x1C

#define I2C_LSM6DSL_FREQ 400000
#define I2C_LSM6DSL_ADDR 0x6A

#define I2C_BMP388_FREQ 400000
#define I2C_BMP388_ADDR 0x77

#define I2C_LTR390_FREQ 400000
#define I2C_LTR390_ADDR 0x53

#define I2C_BME688_FREQ 400000
#define I2C_BME688_ADDR 0x76

#define I2C_MAX30102_FREQ 400000
#define I2C_MAX30102_ADDR 0x57

#define DISPLAY_ROTATION 1 // 2
#define DISPLAY_TIMEOUT 120000
#define HOLD_TIME_TO_LOCK 500

#define LOG_BUFFER_SIZE 100

#define GPS_UPDATE_INTERVAL 1000

#define LOG_1MIN_MS (60*1000)
#define LOG_15MIN_MS (LOG_1MIN_MS*15)
#define LOG_30MIN_MS (LOG_1MIN_MS*30)
#define LOG_1HR_MS (LOG_1MIN_MS*60)
#define LOG_6HR_MS (LOG_1HR_MS*6)
#define LOG_24HR_MS (LOG_1HR_MS*24)

#define LOG_BATTERY_ST_SIZE 10
#define LOG_BATTERY_ST_RATE 1000
#define LOG_MICS6814_ST_SIZE 10
#define LOG_MICS6814_ST_RATE 1000
#define LOG_CAMM8_ST_SIZE 10
#define LOG_CAMM8_ST_RATE 1000
#define LOG_CAMM8_ODO_ST_SIZE 10
#define LOG_CAMM8_ODO_ST_RATE 5000
#define LOG_IMU_ST_SIZE 1000
#define LOG_IMU_ST_RATE 10
#define LOG_IMU_PED_ST_SIZE 10
#define LOG_IMU_PED_ST_RATE 1000
#define LOG_BME688_ST_SIZE 10
#define LOG_BME688_ST_RATE 1000
#define LOG_BME688_GAS_ST_SIZE 10
#define LOG_BME688_GAS_ST_RATE 30000
#define LOG_BMP388_ST_SIZE 10
#define LOG_BMP388_ST_RATE 1000
#define LOG_LTR390_ST_SIZE 10
#define LOG_LTR390_ST_RATE 1000
#define LOG_MAX30102_ST_SIZE 200
#define LOG_MAX30102_ST_RATE 50
#define LOG_MAX30102_EVAL_ST_SIZE 10
#define LOG_MAX30102_EVAL_ST_RATE 1000

#define LOG_BATTERY_LT_SIZE 2000
#define LOG_BATTERY_LT_RATE (LOG_6HR_MS/LOG_BATTERY_LT_SIZE)
#define LOG_MICS6814_LT_SIZE 100
#define LOG_MICS6814_LT_RATE (LOG_6HR_MS/LOG_MICS6814_LT_SIZE)
#define LOG_CAMM8_LT_SIZE 2400
#define LOG_CAMM8_LT_RATE (LOG_6HR_MS/LOG_CAMM8_LT_SIZE)
#define LOG_CAMM8_LT2_SIZE 900
#define LOG_CAMM8_LT2_RATE (LOG_30MIN_MS/LOG_CAMM8_LT2_SIZE)
#define LOG_CAMM8_ODO_LT_SIZE 10
#define LOG_CAMM8_ODO_LT_RATE 1
#define LOG_IMU_PED_LT_SIZE 10
#define LOG_IMU_PED_LT_RATE 1
#define LOG_BME688_LT_SIZE 100
#define LOG_BME688_LT_RATE (LOG_6HR_MS/LOG_BME688_LT_SIZE)
#define LOG_LTR390_LT_SIZE 100
#define LOG_LTR390_LT_RATE (LOG_24HR_MS/LOG_LTR390_LT_SIZE)
#define LOG_MAX30102_EVAL_LT_SIZE 100
#define LOG_MAX30102_EVAL_LT_RATE (LOG_6HR_MS/LOG_MAX30102_EVAL_LT_SIZE)
#define LOG_MAX30102_EVAL_LT2_SIZE 100
#define LOG_MAX30102_EVAL_LT2_RATE (LOG_15MIN_MS/LOG_MAX30102_EVAL_LT2_SIZE)

#define LOG_FLUSH_RATE 10000

#define SDCARD_SPI_HOST     SPI2_HOST
#define SDCARD_SPI_MOSI     GPIO_NUM_41
#define SDCARD_SPI_MISO     GPIO_NUM_42
#define SDCARD_SPI_CLK      GPIO_NUM_40
#define SDCARD_SPI_CS       GPIO_NUM_NC


#ifdef __linux__
#define INPUT_DEBUG
#define USE_EVENT_DBG
#endif

//#define WBL_ACK_DBG
#define USE_LAYOUT_DBG
#define WBL_DEBUG
//#define WBL_LOG_DBG

#ifdef WBL_DEBUG
#define WBL_D(x) puts(x)
#define WBL_DF(x, args...) printf(x, args)
#define WBL_DTIME_BEGIN() int64_t wbl_dtime_begin = micros()
#define WBL_DTIME_END(x) printf("%s Elapsed %llius\n", x, micros() - wbl_dtime_begin)
#else
#define WBL_D(x)
#define WBL_DF(x, args...)
#define WBL_DTIME_BEGIN()
#define WBL_DTIME_END(x)
#endif

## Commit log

2025-06-30 ESP32 S3
2025-07-07 Screen size
    [dpad.blend, dpadarrow.stl, dpadenter.stl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]
2025-07-07 Buttons demo
    [dpad.blend, dpadbuttondemo.stl, dpadring.3mf]
2025-07-09 Variably sized block printing
2025-07-10 I2C For ESP32
2025-07-10 Fix I2C
2025-07-11 Bug fix in imgconv
    [ui.h, wearable.cpp]
2025-07-11 Rename ui.h -> framebuffer.h
2025-07-12 Flow Context
2025-07-12 Update for ESP32
2025-07-14 Button Test
2025-07-15 Interrupts working
2025-07-15 Better states for buttons, error checking on init
    [user_inputs.cpp, user_inputs.h, wearable.cpp]
2025-07-15 Fix odd width less than buffer size
    [consolebuffer.h]
2025-07-16 UI Battery
2025-07-16 Match battery to font
2025-07-17 Fix missing margin (right align)
    [ui.h, wearable.cpp]
2025-07-17 Fix bounds on clock and alignment
    [ui.h, wearable.cpp]
2025-07-18 Try and fix some warnings
    [ui.h, user_inputs.h, wearable.cpp]
2025-07-18 Fix button debounce
2025-07-19 Move I2C struct
2025-07-19 Fixed style not converted to element size before requesting content size
    [ui.h]
2025-07-19 ESP32 model
2025-07-20 Parts layout, power testing
2025-07-21 Log info printing
2025-07-21 Demo done. Fix bad content layout of screen with header off
    [ui.h]
2025-07-22 Disable watchdog timers
2025-07-22 Print current parts
    [PartsBME688_PCB.001.stl, PartsBerryGPS-IMU_PCB.001.stl, PartsESP32_PCB.001.stl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]
2025-07-24 Smaller buttons
    [dpad.blend]
2025-07-24 Scaled with boolean offset for button cap
    [dpad.blend]
2025-07-24 Wire channels
    [dpad.blend]
2025-07-24 Screen frame and updated button board
2025-07-24 New button board
    [dpad Button Board.stl, dpad.blend]
2025-07-25 SMD Button Housing
    [Parts OLED Frame.stl, Parts SMD Button Housing.stl, dpad.blend]
2025-07-25 New frame
    [Parts OLED Frame New.stl]
2025-07-26 New Frame Test
    [Parts OLED Frame New.stl]
2025-07-26 DPAD Button Fram
    [dpad frame.stl, dpad holder.stl, dpad.blend]
2025-07-26 Scale up
    [dpad frame.stl, dpad.blend]
2025-07-26 RDPAD RRING AGAIN
    [dpad frame.stl, dpad.blend]
2025-07-27 OLED Frame
    [Parts OLED Back.stl, Parts OLED Cover.stl]
2025-07-27 Thicken DPAD Frame
    [dpad frame.stl, dpad.blend]
2025-07-27 GPS class
    [dpad.blend]
2025-07-27 Update and get fix if available
    [gps.cpp, wearable.cpp]
2025-07-27 Still waits too long
    [gps.cpp, wearable.cpp]
2025-07-29 Piezo and haptics housing
    [Parts Piezo Resonator and Haptics.stl, Parts Piezo Resonator.stl, Parts Wire Guide.stl]
2025-07-29 Rigidfy Feedback Interface
    [Parts Piezo Resonator and Haptics.stl]
2025-07-30 Power Info
2025-07-31 Fix timer related issues and GPS hangs
    [gps.cpp, wearable.cpp]
2025-07-31 Modify LSM6DSL driver for our I2C
2025-07-31 Need to modify I2C
2025-07-31 Removed static I2C buses
2025-07-31 IMU UI
2025-07-31 Set accelerometer offsets
2025-07-31 Read battery level
2025-07-31 Fix battery voltage scale
    [wbl_system.cpp, wearable.cpp]
2025-07-31 Stabilize battery level reading
    [wbl_system.cpp, wearable.cpp]
2025-07-31 PWM channels
2025-08-01 UV driver
2025-08-01 Datasheet for 602535 500mAh Battery
2025-08-01 Debugging UV Sensor
2025-08-01 Track display state for internal use
2025-08-02 Regulator Info
2025-08-03 Attempt to fix screen flicker with low camera exposure time
    [sh1107.h, wbl_system.cpp]
2025-08-04 Move I2C pins, enable octal PSRAM
2025-08-04 Power management
2025-08-04 Battery short and long term logs
    [config.h, wbl_system.cpp, wearable.cpp]
2025-08-04 Adjust battery readout
2025-08-04 Add CAMM8 and Battery ST and LT
2025-08-05 Fix gps view bug
    [config.h, gps.cpp, ui_gps_log.h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]
2025-08-05 Fix bad aspect ratio
    [gps.cpp, ui_gps_log.h, wearable.cpp]
2025-08-05 Fix GPS read delay, fix GPS communication
    [config.h, gps.cpp, wbl_system.cpp]
2025-08-05 Move I2C BUS 1 SDA again
2025-08-06 New layout image
    [dpad.blend]
2025-08-08 Separate battery voltage and gas log
2025-08-08 UI IMU Info with mini logs
2025-08-08 Fix UI Peripheral Log x=0 bad Y value when log length > plot width
    [ui_peripheral_log.h]
2025-08-09 Voltage and middle baseline
2025-08-09 Attempt at I2C async transactions
